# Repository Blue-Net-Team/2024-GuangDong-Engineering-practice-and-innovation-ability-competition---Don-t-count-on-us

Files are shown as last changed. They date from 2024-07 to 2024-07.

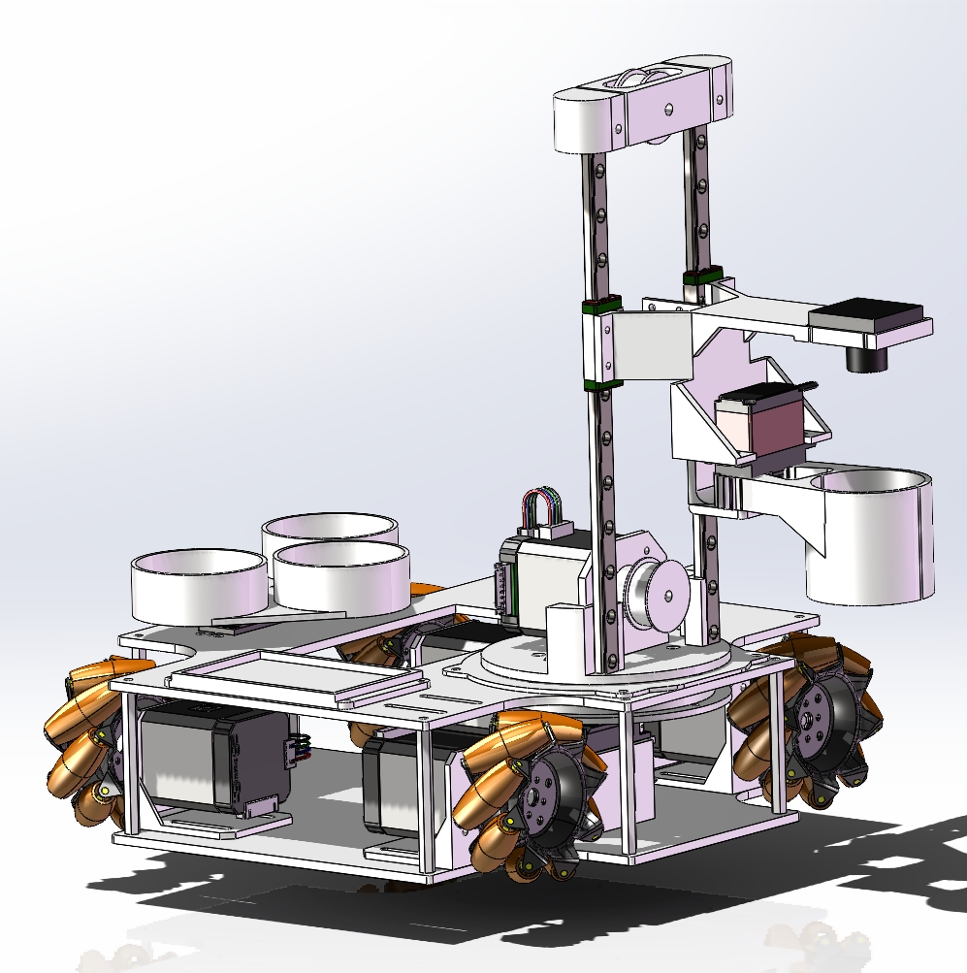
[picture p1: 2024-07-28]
Pic/4.png

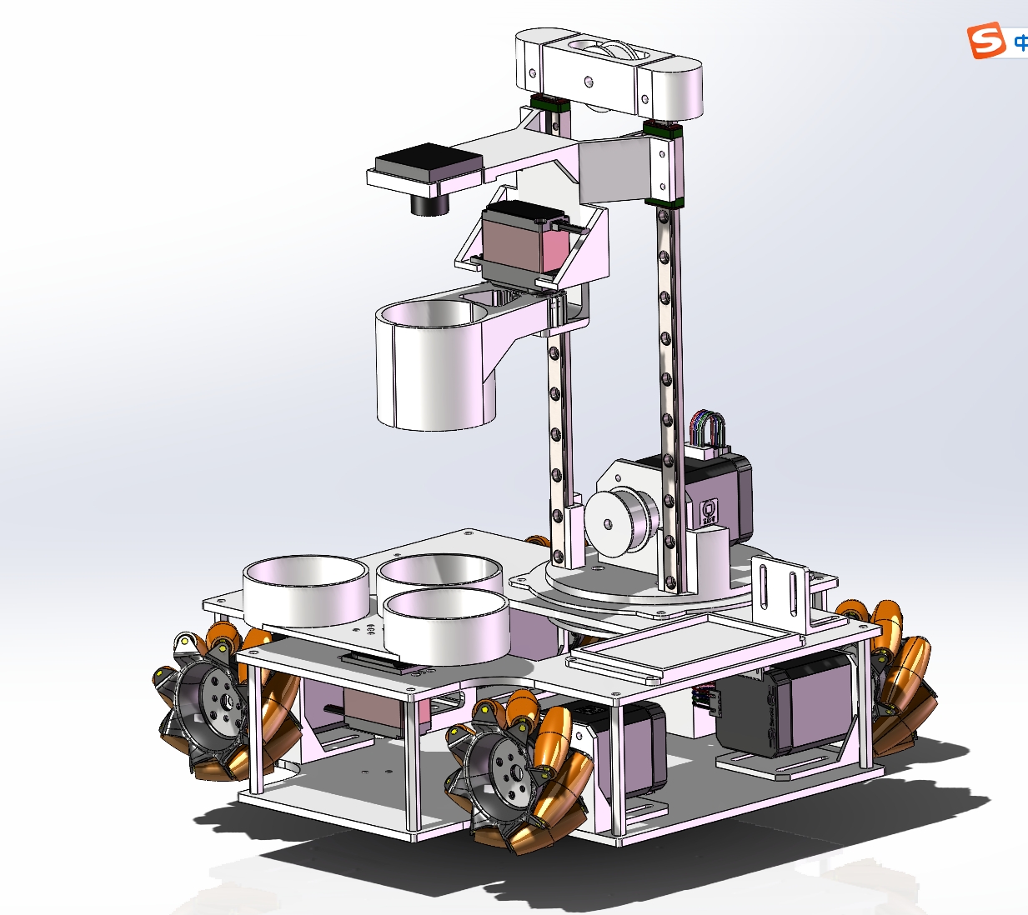
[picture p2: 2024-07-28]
Pic/2.png

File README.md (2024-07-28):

# 2024年工创智慧物流搬运赛道——不要指望我们队

## 1. 项目简介

本项目是针对**2024年工程实践创新大赛 智慧物流搬运**的完整项目，包括代码、电路设计、结构设计等。

## 2. 小队成员

- 吉泧均——结构设计
- [林哲涵](https://gitee.com/purebrandy)——电控设计
- [何云峰](https://gitee.com/iven_he)——视觉识别

## 3. 文件夹说明

本文件夹中包含了一下主要文件夹

- `Vision`：视觉识别代码
- `Embedded`：电控代码
- `Structure`：结构设计(使用SolidWorks2023或者以上版本打开)
- `Doc`: 项目文档
- `Pic`: 模型图片
- `LICENSE`: 项目开源许可证
- `README.md`: 项目说明文件

## 获奖情况

实时是，此代码并未获奖，分析前后原因，视觉方面鲁棒性不够高。在设备方面，升降机构的电机存在不明确的问题，有时候会出现堵转的情况，有时候会直接断电，导致整个设备无法正常运行，这个问题原因仍不明确。

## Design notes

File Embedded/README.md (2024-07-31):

# 2024工创电控部分代码

## 介绍
2024年工创物流车电控部分代码
内容包括
- 闭环步进电机驱动
- 麦克纳姆轮运动学解算
- 270度舵机驱动
- 扫码模块读取解码
- 与数码管显示的通信协议
- 与树莓派视觉的通信协议

## 开发平台
STM32F407VET6

## 开发环境
Keil5 MDK
FreeRTOS

## 开发说明
本代码基于单片机的实时操作系统FreeRTOS开发

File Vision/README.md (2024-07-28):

# 2024年工创智慧物流搬运赛道——不要指望我们队(视觉识别)

## 1. 代码简介

本项目是针对**2024年工程实践创新大赛 智慧物流搬运**的视觉识别代码

## 2. 小队成员

- 吉泧均——结构设计
- [林哲涵](https://gitee.com/purebrandy)——电控设计
- [何云峰](https://gitee.com/iven_he)——视觉识别

## 3. 文件说明

本文件夹中包含了一下主要文件

- `main.py`：项目主文件，封装了所有回应电控stm32的需求的函数
- `img_trans.py`:远程图传文件，其中类
  - `VideoStreaming`是用于传输图像的类，在树莓派上运行
  - `ReceiveImg`是用于接受远程图传图像的类，在本地电脑运行
- `detector.py`：存放识别器的文件，其中类
  - `ColorDetector`是用于识别颜色的颜色识别器
  - `LineDetector`是用于识别直线状态的识别器，包含识别直线角度以及直线距离
- `DEBUG.py`：用于调试的文件，其中类
  - `Debug`是用于调试的类，继承了主文件的类，可以在调试时使用，直接修改主文件的代码就可以在调试时使用
- `UART.py`：串口通信文件，其中类
  - `UART`是用于串口通信的类，继承了`pyserial`库的`Serial`类，添加了**包头包尾**的发送方式以及**整形数据**和**整形数组**的发送方式

## 4. 使用说明

本项目需要在本地电脑和树莓派上都克隆此项目

```bash
git clone https://gitee.com/blue-net-vision/physical-distribution-car.git
```

在远程调试过程中，在树莓派上运行`img_trans.py`文件打开图传服务器，需要注意的是

- **树莓派和本地电脑需要在同一个局域网下**
- **先运行`img_trans.py`文件，再运行`DEBUG.py`文件**
- **`img_trans,py`已经将相关IO输出(print)关闭，如果需要开启需要自行取消注释**

然后打开`DEBUG.py`文件，运行相关的阈值调试函数，在图传调试的时候，将DEBUG实例化的参数改为True;如果不使用图传摄像头，就将DEBUG实例化的参数改为False

### 调试的过程中会产生以下文件

- `R.json`：存放红色阈值的文件
- `G.json`：存放绿色阈值的文件
- `B.json`：存放蓝色阈值的文件
- `line.json`：存放直线canny阈值的文件
- `color_oc.json`：存放物料颜色识别的开闭运算参数的文件
- `line_oc.json`：存放直线识别的开闭运算参数的文件
- `circle1.json`：存放物料盘上夹取物料的基准圆信息的文件
- `radius.json`：在物料盘上夹取物料的时候的最小和最大外接圆识别半径

## 代码解读

在此代码中，以下代码是用于调整图像的范围的，即裁剪图像，过滤无关的区域，使得后续的识别更加准确。

```python
self.img = self.read_cap()
# [130:370, :]是裁剪图像的范围，需要根据具体情况调整
self.img = self.img[130:370, :]
```

### 1. `main.py`——在树莓派上直接运行的主文件

#### 1.1 region 参数加载

在参数加载的region区域，设置了各种识别过程中的参数，包括阈值，开闭运算参数，基准圆信息等。前两个以大写开头的字典视为常量字典，用于在后续的识别过程中使用。

#### 1.2 类Solution

这是一个包含代码顶层抽象逻辑的**解决方案类**，继承了`detector.py`文件中的`ColorDetector`和`LineDetector`类，使后续的代码更加灵活。以大写字母开头的函数在该类中属于最顶层接口，反之为次级接口。

在该类中，可以注意到`__init__`函数中有两个部分，一个是类自身的init，另一个是在`__init__`函数之外编写的`init_part1`,其中，`init_part1`函数是便于后续`DEBUG.py`文件中**调试类**继承时候的超类初始化。

`read_cap`函数是用于读取图传图像的函数，这个函数的设计是为了解决摄像头的ID号突然发生改变导致无法读取图像的问题，并且返回值不再包含`cv2.VideoCapture.read()`返回值中的bool标签，而是直接返回图像。

`send_msg`函数是用于发送串口数据的函数，只需要向里面传递整型、整型数组、字符串等数据即可以从串口发送对应的字符ascii码。其中，整型数组(list/tuple)是针对圆环坐标矫正的数据发送，整型是针对物料夹取信号和直线角度矫正的数据发送。此函数在初期框架搭建的时候具有缺陷，只能使用单一的包头包尾，否则需要针对不同的包头包尾设计不同的发送函数和修饰器。

`Detect_color`函数是用于识别颜色的函数，需要电控提供相关的颜色索引 (0红 1绿 2蓝),返回值是是否识别到这个颜色，只会返回True，如果没有匹配的颜色，会继续循环进行识别。在此处识别的逻辑是，先对图像进行hsv的图像二值化，然后将白色(符合颜色阈值的区域)区域做最小外接圆匹配(相关参数文件位于`radius.json`)，然后圈出的圆再与基准圆(相关参数文件位于`circle1.json`)进行比较，如果两个圆的重叠面积比例(以基准圆面积为分母)大于225行的0.48，就认为匹配到颜色。

`CORRECTION_angle`函数是用于矫正直线角度的，使用此函数需要确保摄像头的视野范围可以**看清楚**基准直线，如果看不清或者看不见的话就不会有返回数据。在此函数中，首先对图像进行canny边缘检测，然后对边缘检测的图像进行霍夫直线检测，最后对检测到的直线进行角度的计算，返回值是直线的角度。244行的90是基准直线的角度，这个数值取决于摄像头摆放的角度。

`LOCATECOLOR`函数是用于矫正色环的函数，使用此函数需要确保摄像头的视野范围可以**看清楚**圆环，如果看不清或者看不见的话就不会有返回数据，而是循环识别，知道识别到圆环。在此函数中，首先对图像进行hsv的图像二值化，进行相关的开闭运算(相关参数文件位于`circle_oc.json`)，然后对图像进行霍夫圆检测，这个过程循环10次，如果没识别到不计入，然后计算平均值，并且用基准圆(相关参数文件位于`circle2.json`)的圆心坐标做差，返回值是圆心坐标的差值。可以直接对基准圆文件进行修改，这样比较方便，其中，X调大的时候，物料摆放偏左， y调小的时候，物料摆放偏下

`__call__`是类的主函数调用，调用方法比较特殊，属于类的特殊函数

```python
# 用以下方法调用__call__函数
Solution()()
```

`circle_intersection_area`函数是用于计算两个圆的重叠面积的函数，用于在`Detect_color`函数中计算两个圆的重叠面积比例，传入尾缀为0的参数是第一个圆的圆心坐标和半径，传入尾缀为1的参数是第二个圆的圆心坐标和半径，返回值是两个圆的重叠面积。

### 2.`detector.py`——存放识别器的文件

本文件识别逻辑比较基础，霍夫算法检测查看csdn或者百度，此处不再解读

### 3.`DEBUG.py`——用于调试的文件

此类有4个顶层接口，用于外界直接调用，`SetCircleThresholds` `SetColorThresholds` `SetLineThresholds`分别用于设置圆环阈值，颜色阈值，直线阈值

底层函数接口简单，不再解读

### 4.`UART.py`——串口通信文件

此代码框架成型早，没有考虑太多问题，一开始将包头包尾封装进修饰器，然后发现不同的条件发送的数据包头包尾应该不同，，所以在后续代码中添加了过多的针对性修饰器和发送函数，导致代码冗余，不够简洁，但是功能齐全，可以直接使用。`read`函数比较完美，重写了父类`sreial`的`read`函数，可以通过包头包尾来读取不定长度的数据，但是每次只能读一个字节，对于`\r\n`的读取不够完美，需要后续优化。

## 获奖情况

实时是，此代码并未获奖，分析前后原因，鲁棒性不够高，并且代码冗余，不够简洁，后续需要优化。与此同时，应该将main文件中225行的最小重叠面积比例调小，以及`ciecle1.json`文件中的基准圆半径调大，这样可以提高识别的鲁棒性。在设备方面，升降机构的电机存在不明确的问题，有时候会出现堵转的情况，有时候会直接断电，导致整个设备无法正常运行，这个问题原因仍不明确。在后续的比赛中，视觉方面决定放弃hsv识别方案，转而使用深度学习的方案，这样可以提高识别的准确性，鲁棒性，以及适应性。

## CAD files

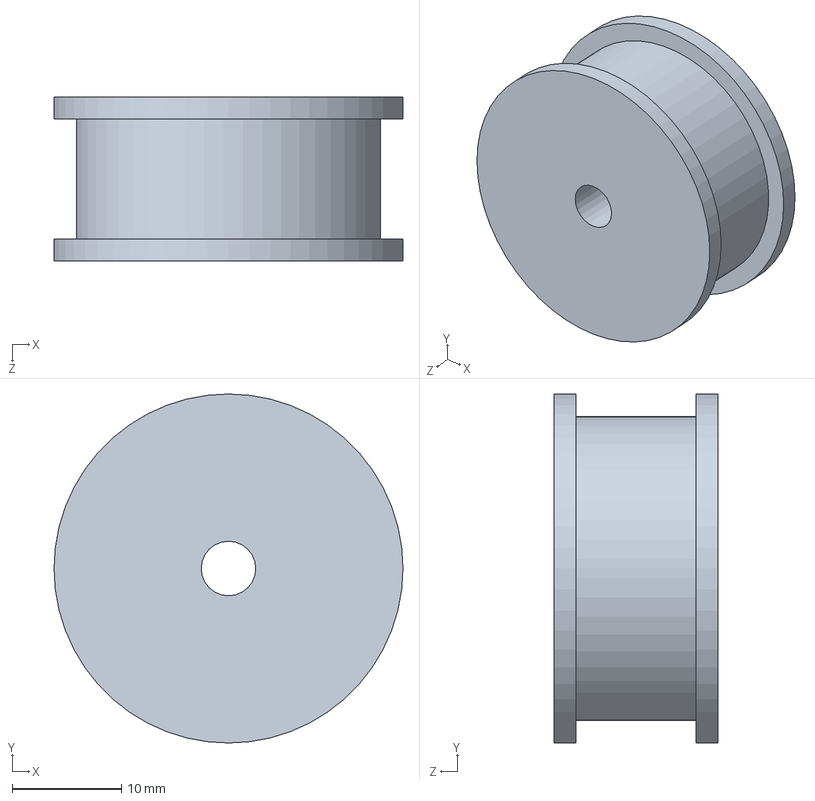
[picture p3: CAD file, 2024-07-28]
Structure/AF同步轮.SLDPRT
32.0 x 32.0 x 15.0 mm

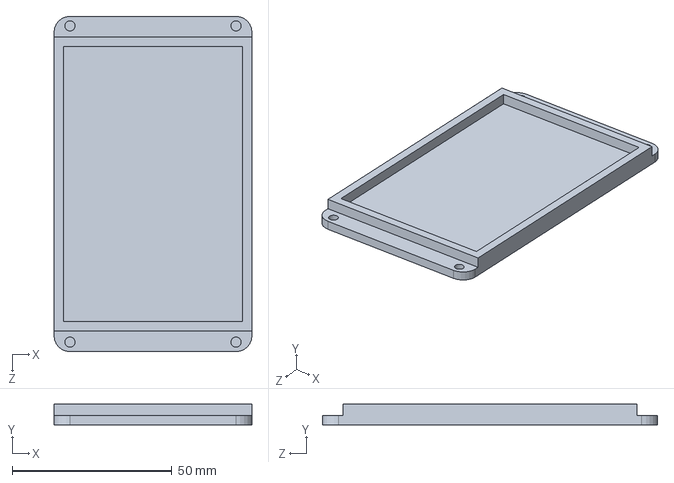
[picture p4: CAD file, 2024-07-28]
Structure/树莓派固定.SLDPRT
62.0 x 6.50 x 105.0 mm

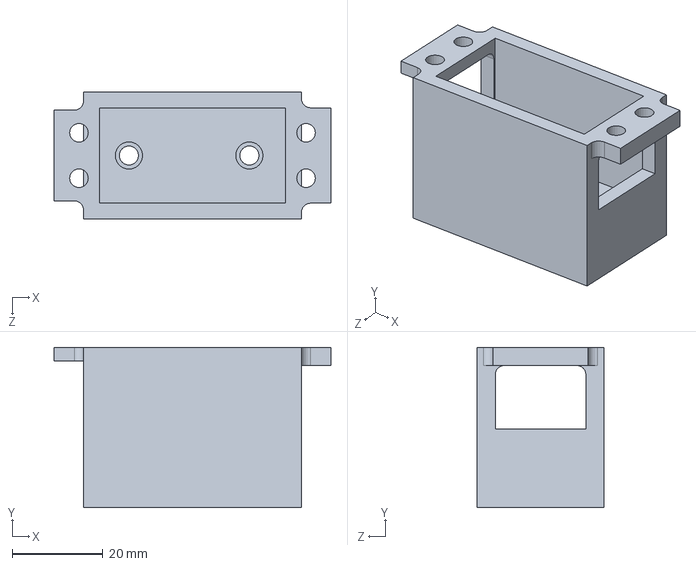
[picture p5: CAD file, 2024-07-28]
Structure/舵机固定支架.SLDPRT
61.0 x 35.3 x 28.0 mm

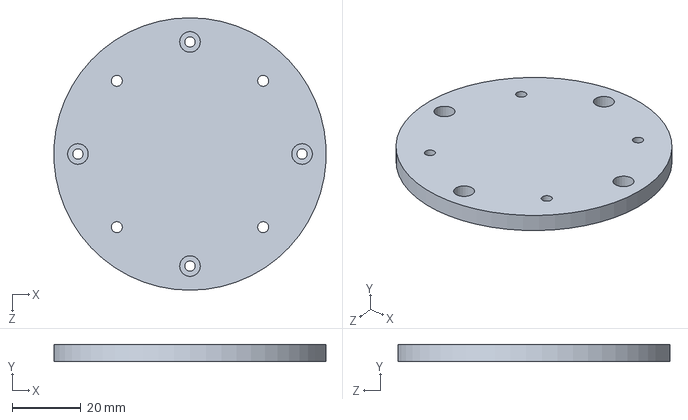
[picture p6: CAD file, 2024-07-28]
Structure/旋转顶盖.SLDPRT
78.9 x 5.00 x 79.0 mm

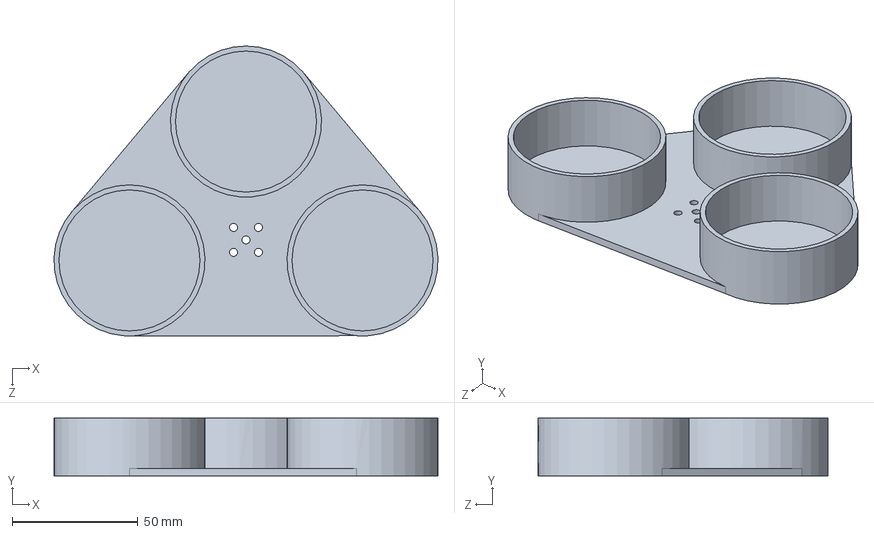
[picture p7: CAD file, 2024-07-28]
Structure/载物盘.SLDPRT
152.5 x 23.0 x 115.2 mm

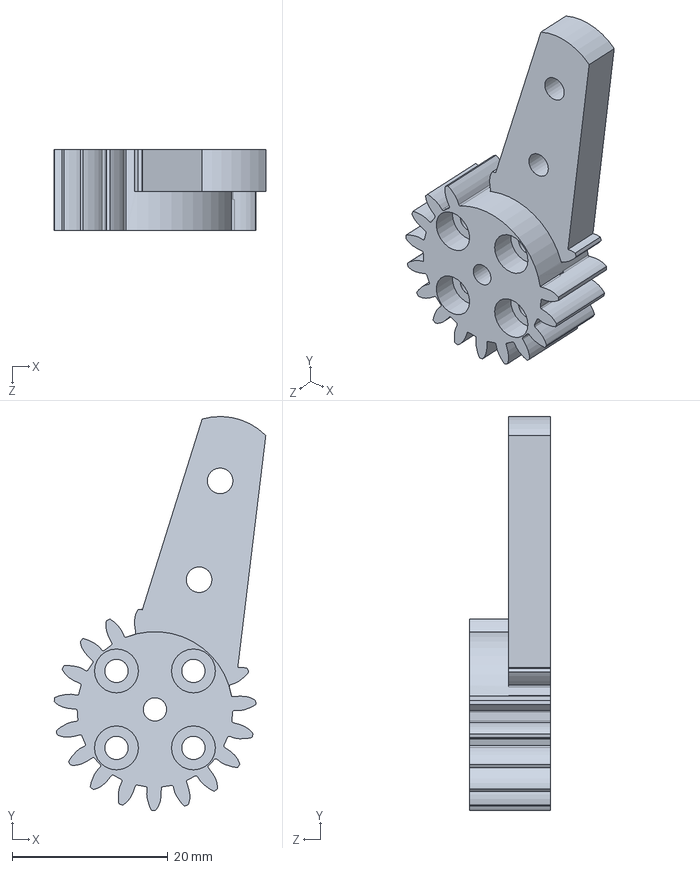
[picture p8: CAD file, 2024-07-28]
Structure/机械爪左便携支架.SLDPRT
27.2 x 50.7 x 10.5 mm

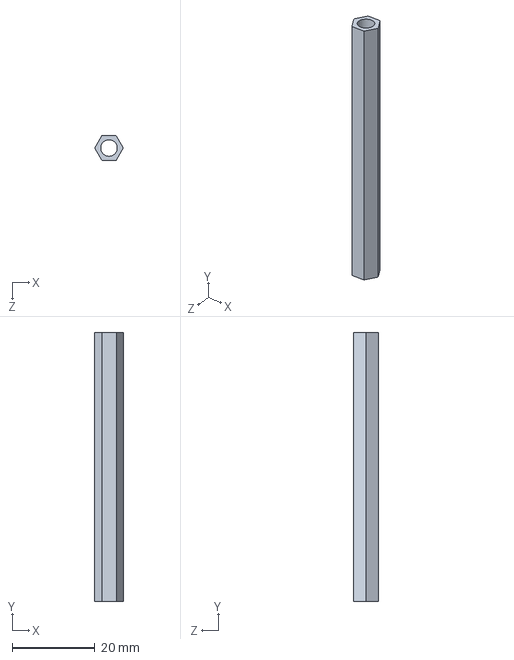
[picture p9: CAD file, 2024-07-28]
Structure/铜柱M4×65.SLDPRT
6.93 x 65.0 x 6.02 mm

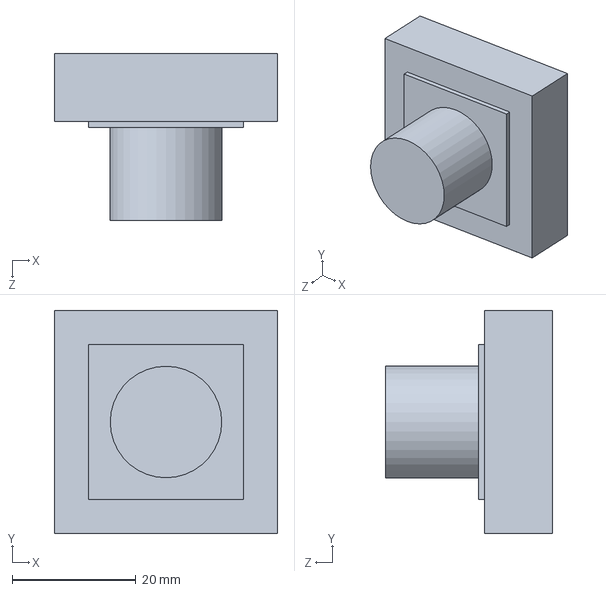
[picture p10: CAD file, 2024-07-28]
Structure/宇宙无敌暴龙之眼.SLDPRT
36.0 x 36.0 x 27.0 mm

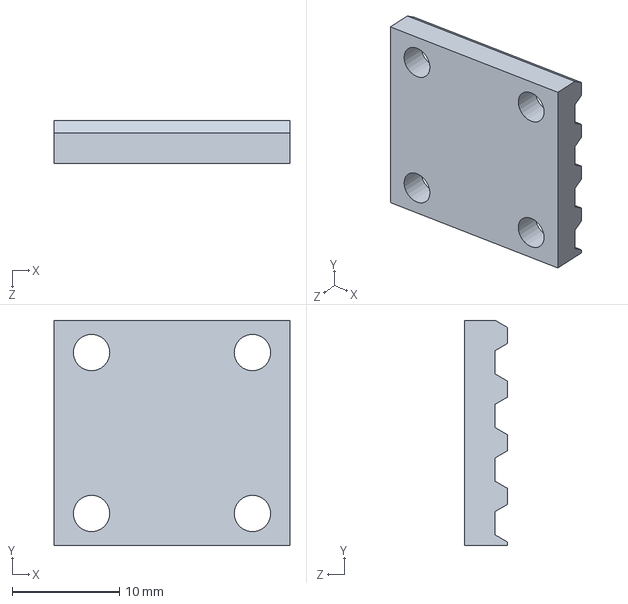
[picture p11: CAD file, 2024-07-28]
Structure/同步带压板.SLDPRT
22.0 x 21.0 x 4.00 mm

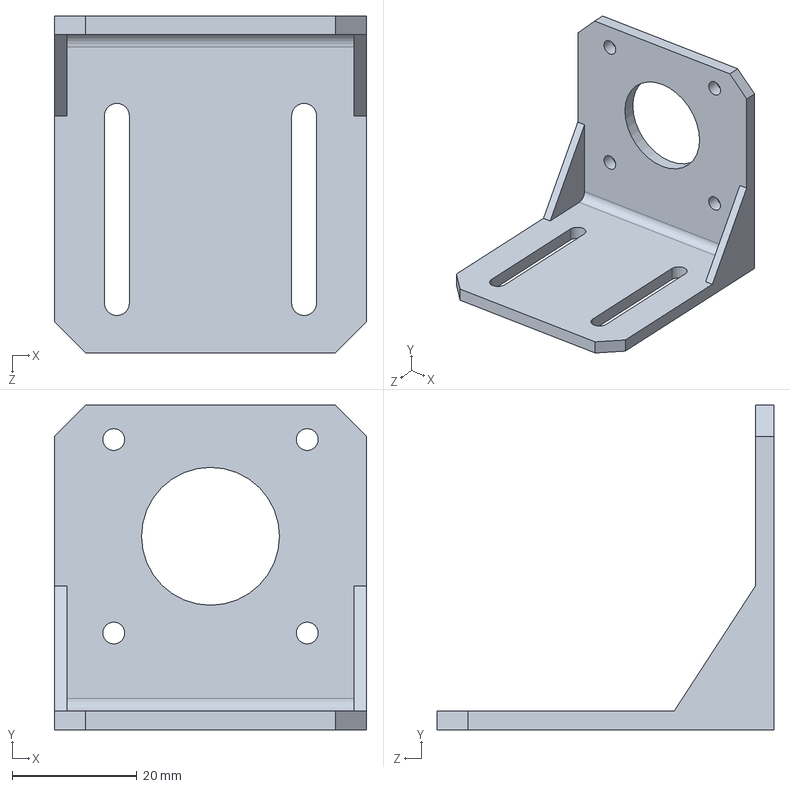
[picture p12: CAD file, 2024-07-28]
Structure/42步进电机支架.SLDPRT
50.0 x 52.0 x 54.0 mm

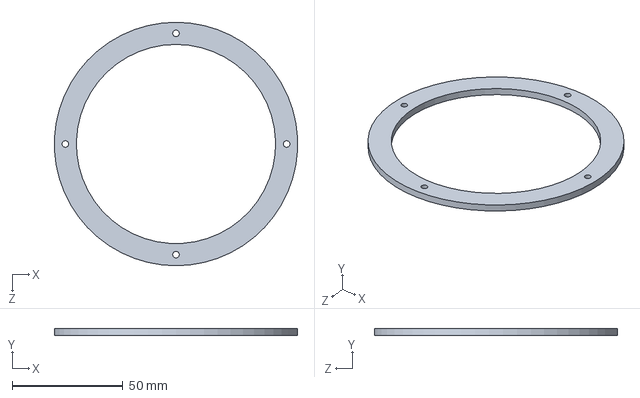
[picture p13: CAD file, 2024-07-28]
Structure/云台底盘.SLDPRT
109.8 x 3.00 x 110.0 mm

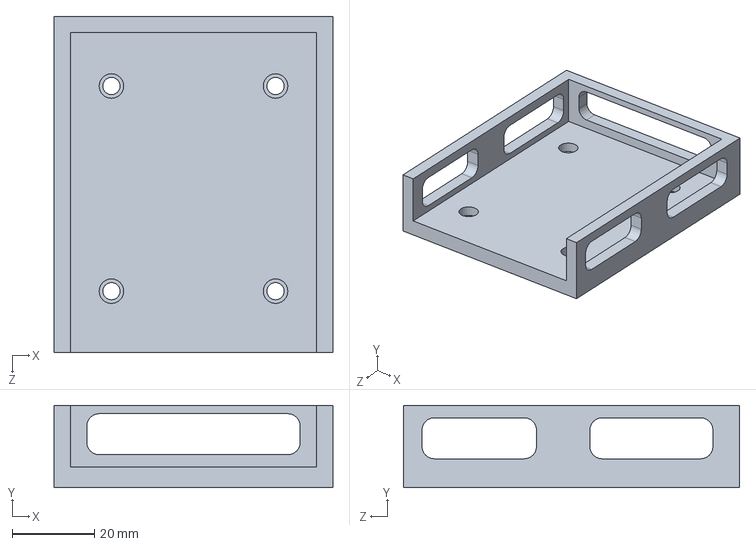
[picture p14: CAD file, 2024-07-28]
Structure/电池支架.SLDPRT
68.0 x 20.0 x 82.0 mm

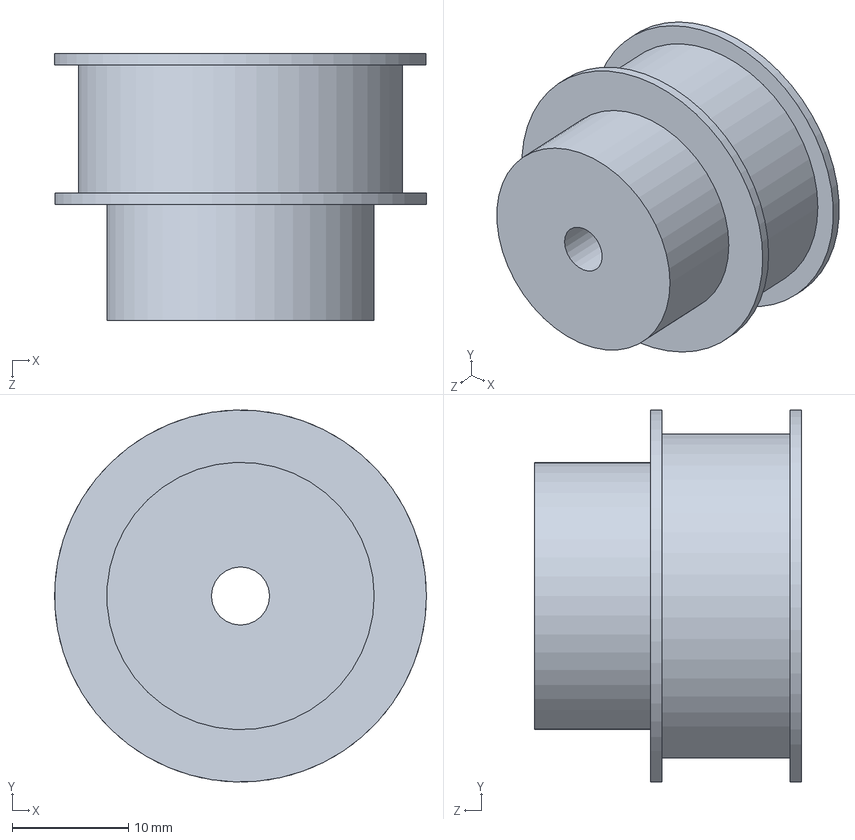
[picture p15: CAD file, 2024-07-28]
Structure/BF同步轮.SLDPRT
32.0 x 32.0 x 23.0 mm

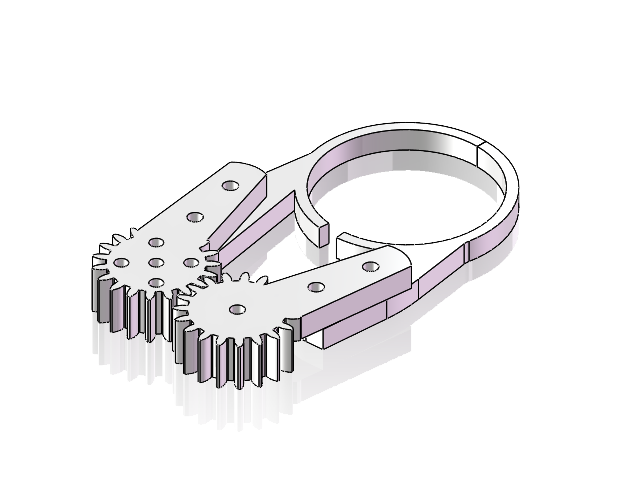
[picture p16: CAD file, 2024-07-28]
Structure/机械爪装配.SLDASM
机械爪左便携支架
机械爪右便携支架
便携爪子初始 x 2

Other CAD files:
Structure/机械爪2.SLDASM
Structure/MGN9-250.SLDASM
Structure/42步进电机.SLDASM
Structure/mecanum wheel.SLDASM
Structure/上同步轮固定.SLDPRT
Structure/上板.SLDPRT
Structure/下固定板.SLDPRT
Structure/二维码模块上层固定架2.SLDPRT
Structure/二维码模块固定板.SLDPRT
Structure/云台顶盘.SLDPRT
Structure/便携爪子初始.SLDPRT
Structure/便携爪子初始加长.SLDPRT
Structure/升降链接6.SLDPRT
Structure/同步轮.SLDPRT
Structure/底板.SLDPRT
Structure/摄像头固定支架.SLDPRT
Structure/摄像头平台.SLDPRT
Structure/旋转底层.SLDPRT
Structure/机械爪右2.SLDPRT
Structure/机械爪右便携支架.SLDPRT
Structure/机械爪右初始.SLDPRT
Structure/机械爪左2.SLDPRT
Structure/机械爪左初始.SLDPRT
Structure/树莓派固定2.SLDPRT
Structure/法兰盘.SLDPRT
Structure/滑台.SLDPRT
Structure/滑轨.SLDPRT
Structure/爪子2.SLDPRT
Structure/物料.SLDPRT
Structure/电池支架2.SLDPRT
Structure/舵机.SLDPRT
Structure/轴承.SLDPRT

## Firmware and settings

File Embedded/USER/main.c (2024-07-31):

#include "main.h"

/********************
	声明：
	绝大部分移植于gitee蓝网电控库 "@D2zling"
	具体详细参照gitee蓝网电控库“2024工创电控代码”
*******************/

/*
r"""
*********************************************
? ? ? ? ? ? ? ? ? ?_ooOoo_
? ? ? ? ? ? ? ? ? o8888888o
? ? ? ? ? ? ? ? ? 88" . "88
? ? ? ? ? ? ? ? ? (| -_- |)
? ? ? ? ? ? ? ? ? O\ ?= ?/O
? ? ? ? ? ? ? ?____/`---'\____
? ? ? ? ? ? ?.' ?\\| ? ? |// ?`.
? ? ? ? ? ? / ?\\||| ?: ?|||// ?\
? ? ? ? ? ?/ ?_||||| -:- |||||- ?\
? ? ? ? ? ?| ? | \\\ ?- ?/// | ? |
? ? ? ? ? ?| \_| ?''\---/'' ?| ? |
? ? ? ? ? ?\ ?.-\__ ?`-` ?___/-. /
? ? ? ? ?___`. .' ?/--.--\ ?`. . __
? ? ? ."" '&lt; ?`.___\_&lt;|>_/___.' ?>'"".
? ? ?| | : ?`- \`.;`\ _ /`;.`/ - ` : | |
? ? ?\ ?\ `-. ? \_ __\ /__ _/ ? .-` / ?/
======`-.____`-.___\_____/___.-`____.-'======
? ? ? ? ? ? ? ? ? ?`=---='

? ? ? ? ? ? 佛祖保佑 ? ? ? 工创省一
^^^^^^^^^^^^^^^^^^^^^^^^^^^^^^^^^^^^^^^^^^^^^
"""
*/

/*
舵机      PD12	   PD13	   PD14	   
通道	    CH1	     CH2		 CH3		   
对应      爪子     货舱    云台
ServoNum   0        1       2
*/

int main(void)
{
	NVIC_PriorityGroupConfig(NVIC_PriorityGroup_4);			//设置系统中断优先级分组4
	delay_init(168);										  //延时初始化
	usart3_init(9600);										//树莓派通信端口
	scan_qr_code_Init();									//扫码初始化
	digital_tube_Init();									//数码管模块初始化
	MOTOR_UP_Down_Init();									//脉冲控制升降爪初始化
	usart_ctrl_steeping_motor_Init();			//串口控制步进电机初始化
	servo_Init(20000 - 1, 84 - 1);				//舵机控制初始化

	package_Init();											  //串口数据包软件初始化
	motor_soft_Init();										//电机软件初始化
	
	//舵机启动复位
	ServoAngle(0,Claw_Open); //150 228 205 130 Claw_Open Claw_Catch Claw_Open_Small Claw_Open_Big
	ServoAngle(1,Warehouse_running); //108 10 208 120 Warehouse_1 Warehouse_2 Warehouse_3 Warehouse_running
	ServoAngle(2,Clound_Reset); //90 268  Cloude_Work  Clound_Reset
}

void tast_loop(void)
{
  static char* qr_data = NULL;						//扫码数据包
	static int* move = NULL;							//半成品/成品区动作
	static u8 *color_data = NULL;						//颜色数据

	char i;												//计数变量
	int angle_warehouse = 108;
	
	delay_ms(2000);	//等待电机启动
	                                                                                                                                                  ;
	while(1)
	{

//		ServoAngle(2,Cloude_Work);
					
//			while(1);
		
		/*********第一轮**********/
		{	//**前往原料区**//
		change_xyw_speed_no_quene(0,-91,0);//-90
		delay_ms(300);

		change_xyw_speed_no_quene(157,0,0);
		delay_ms(1200);
		
		change_xyw_speed_no_quene(0,0,0);
		delay_ms(1000);
		
		while(qr_data == NULL) qr_data = get_qr_code_data();//获取二维码并显示
		digital_tube_Display(qr_data);

		delay_ms(200);
			
		ServoAngle(0,Claw_Open);//爪子开始工作
		ServoAngle(2,Cloude_Work);//云台开始工作
		
		change_xyw_speed_no_quene(146,26,0);
		delay_ms(1200);

		change_xyw_speed_no_quene(0,0,0);
		delay_ms(100);
		
		delay_ms(500);
		}
					
		//**一轮获取物料**//
		for(i = 0;i <= 2; i++)
		{
			SendByte('c',qr_data[i]-1);//呼叫树莓先生识别颜色
			//调试：可注释掉假装识别到
			while(1)
			{
				color_data = get_color_data();
				if(color_data[0] == '1')
				{
					color_data = NULL;
					break;
				}
			}
			//按顺序决定货仓舵机角度
			if(i == 0) 		angle_warehouse = Warehouse_1;
			else if(i == 1) 	angle_warehouse = Warehouse_2;
			else if(i == 2) 	angle_warehouse = Warehouse_3;
			ServoAngle(1,angle_warehouse);//108 10 203
			
			if(i <= 1)
			{
				Claw_Catch_material();//获取原料
				delay_ms(500);
			}
			if(i == 2)
			{
					Claw_Up_Down(0,Material_Height);//下降
					ServoAngle(0,Claw_Catch);//抓取角度：225
					delay_ms(300);
					ServoAngle(2,Clound_Reset);//云台旋转放置：270
					Claw_Up_Down(1,Material_Height);//升高
					Claw_Up_Down(0,Put_Height);//下降
					ServoAngle(0,Claw_Open_Small);//松开小角度：200
					delay_ms(100);
					Claw_Up_Down(1,Put_Height);//升高
					ServoAngle(0,Claw_Open);
					//放置完最后一个物料后，边走边复位云台
					change_xyw_speed_no_quene(132,0,-65);ServoAngle(1,Warehouse_running);
					delay_ms(1200);
					change_xyw_speed_no_quene(0,0,0);ServoAngle(2,Cloude_Work);
					delay_ms(600);
			}

		}

		{//**一轮物料盘到暂存区**//

			if(qr_data[0] == '1')//根据二维码数字决定先到哪个位置
			{	
				change_xyw_speed_no_quene(100,0,0);
				delay_ms(1100);
				change_xyw_speed_no_quene(0,0,0);
				delay_ms(100);
			}
			else if(qr_data[0] == '2')
			{	
				change_xyw_speed_no_quene(100,0,0);
				delay_ms(1400);
				change_xyw_speed_no_quene(0,0,0);
				delay_ms(100);
			}
			else if(qr_data[0] == '3') 	
			{
				change_xyw_speed_no_quene(100,0,0);
				delay_ms(1800);
				change_xyw_speed_no_quene(0,0,0);
				delay_ms(100);
			}
		
		}
		
		//**一轮半成品区放置三个物料**//
		for(char i = 0; i <= 2; i++)
		{
			move = get_way(qr_data[i]);//获取下一个目标
			change_xyw_speed_no_quene(move[1],0,0);
			delay_ms(move[0]);

			change_xyw_speed_no_quene(0,0,0);
			delay_ms(100);
			
			Claw_Up_Down(0,Camera_Height);//降下摄像头
			vTaskDelay(500);
			
			for(char j =0; j<10; j++)//刷新串口数据
			{SendByte('C',qr_data[i]-1);delay_ms(100);}
			
			location_task(qr_data[i]-1);//树莓先生的色环矫正环节

			Claw_Up_Down(1,Camera_Height);//升起摄像头
			delay_ms(500);
			
			//按顺序决定货仓舵机角度
			if(i == 0) 		angle_warehouse = Warehouse_1;
			else if(i == 1) 	angle_warehouse = Warehouse_2;
			else if(i == 2) 	angle_warehouse = Warehouse_3;
			ServoAngle(1,angle_warehouse);//108 10 203
			
			PutOn_Ground();//放置物料到地上	

		}

		//**半成品区捡起三个物料**//
		for(char i = 0; i < 3; i++)
		{
			move = get_way(qr_data[i]);		//获取下一个目标
			change_xyw_speed_no_quene(move[1],0,0);
			delay_ms(move[0]);

			change_xyw_speed_no_quene(0,0,0);
			delay_ms(100);
			
			//按顺序决定货仓舵机角度
			if(i == 0) 		angle_warehouse = Warehouse_1;
			else if(i == 1) 	angle_warehouse = Warehouse_2;
			else if(i == 2) 	angle_warehouse = Warehouse_3;
			ServoAngle(1,angle_warehouse);//108 10 203 
			
			Catch_From_Ground();//从地面取回物料放回货仓
			
			delay_ms(500);
		}
		
		ServoAngle(1,Warehouse_running);

		{//**暂存区到成品区**//
			change_xyw_speed_no_quene(0,-100,0);//-90
			delay_ms(200);
			change_xyw_speed_no_quene(0,0,0);//-90
			delay_ms(300);
			
			
			//根据二维码数字补回距离
			if(qr_data[2] == '1')  
			{change_xyw_speed_no_quene(100,0,0);delay_ms(670);}
			else if(qr_data[2] == '2') 
			{change_xyw_speed_no_quene(100,0,0);delay_ms(335);}
			else if(qr_data[2] == '3') 
			{change_xyw_speed_no_quene(0,0,0);delay_ms(100);}

			change_xyw_speed_no_quene(0,0,0);delay_ms(500);
			
			change_xyw_speed_no_quene(133,0,-65);
			delay_ms(1300);
			change_xyw_speed_no_quene(0,0,0);
			delay_ms(500);
			
			//直线矫正
			Claw_Up_Down(0,Line_Height);//降下摄像头
			delay_ms(500);
			Line_task();
			Claw_Up_Down(1,Line_Height);//升起摄像头
			delay_ms(500);

			//根据二维码数字决定到哪个位置
			if(qr_data[0] == '1') 		
			{	
				change_xyw_speed_no_quene(95,12,0);
				delay_ms(870);
				change_xyw_speed_no_quene(0,0,0);
			}
			else if(qr_data[0] == '2')
			{	
				change_xyw_speed_no_quene(100,15,0);
				delay_ms(1150);
				change_xyw_speed_no_quene(0,0,0);
				delay_ms(100);
			}
			else if(qr_data[0] == '3') 	
			{
				change_xyw_speed_no_quene(100,10,0);
				delay_ms(1600);
				change_xyw_speed_no_quene(0,0,0);
				delay_ms(100);
			}
			change_xyw_speed_no_quene(0,0,0);
			vTaskDelay(500);
		
		//*成品区放置物料*//
			 for(char i = 0; i < 3; i++)
		{
			move = get_way(qr_data[i]);		//获取下一个目标
			change_xyw_speed_no_quene(move[1], 0, 0);
			delay_ms(move[0]);
			
			change_xyw_speed_no_quene(0,0,0);
			delay_ms(100);
			
			Claw_Up_Down(0,Camera_Height);//降下摄像头
			delay_ms(500);
			
			for(char j =0; j<10; j++)//刷新串口数据
			{SendByte('C',qr_data[i]-1);delay_ms(100);}
			
			location_task(qr_data[i]-1);//色环矫正

			Claw_Up_Down(1,Camera_Height);//升起摄像头
			delay_ms(500);
			
			//按顺序决定货仓舵机角度
			if(i == 0) 		angle_warehouse = Warehouse_1;
			else if(i == 1) 	angle_warehouse = Warehouse_2;
			else if(i == 2) 	angle_warehouse = Warehouse_3;
			ServoAngle(1,angle_warehouse);//108 10 203
			
			PutOn_Ground();//放置物料到地上
		}
			 
		ServoAngle(1,Warehouse_running);
		
	}
		//复位count
		 for(char i = 0; i < 3; i++)
				move = get_way(qr_data[i]);
	
			if(qr_data[2] == '1') //根据二维码数字补全距离
				{change_xyw_speed_no_quene(50,0,0);delay_ms(100);}
			else if(qr_data[2] == '2') 
				{change_xyw_speed_no_quene(-100,0,0);delay_ms(350);}
			else if(qr_data[2] == '3') 
				{change_xyw_speed_no_quene(-100,0,0);delay_ms(690);}

			change_xyw_speed_no_quene(0,0,0);delay_ms(300);
		 
		 {//**回到原料区**//			 

			 change_xyw_speed_no_quene(-100,-70,0);
			 delay_ms(500);
			 
			 change_xyw_speed_no_quene(-100,15,0);
			 delay_ms(450);
		 
			 change_xyw_speed_no_quene(0,0,0);
			 delay_ms(500);
			 
			 change_xyw_speed_no_quene(-93,0,66);
			 delay_ms(1200);
			 
			 change_xyw_speed_no_quene(0,0,0);
			 delay_ms(600);  
			 
			  //直线矫正
			 Claw_Up_Down(0,Line_Height);//降下摄像头
			 delay_ms(500);
			 Line_task();
			 Claw_Up_Down(1,Line_Height);//升起摄像头
			 delay_ms(500);
			 
			 change_xyw_speed_no_quene(-150,0,0);
			 delay_ms(1400);
			 
			 change_xyw_speed_no_quene(0,0,0);
			 delay_ms(400);
			 
			 change_xyw_speed_no_quene(-114,0,55);
			 delay_ms(1450);
			 
			 change_xyw_speed_no_quene(0,0,0);
			 delay_ms(400);
			 
			change_xyw_speed_no_quene(-100,0,0);
			 delay_ms(130);
			 
			 change_xyw_speed_no_quene(0,0,0);
			 delay_ms(600);

		 }
		 
		 //********第二轮********//
		 
		 {//二轮原料获取
			for(char j = 0; j < 10 ;j++)//刷新串口数据
			 {
				 SendByte('c',qr_data[3] - 1);
				 color_data = get_color_data();
				 delay_ms(100);
			 }
			
			 
			for(i = 3;i <= 5; i++)
		{
			
			SendByte('c',qr_data[i] - 1);//颜色判断
			
			while(1)
			{
				color_data = get_color_data();
				if(color_data[0] == '1')
				{
					color_data = NULL;
					break;
				}
			}
			//按顺序决定货仓舵机角度
			if(i == 3) 		angle_warehouse = Warehouse_1;
			else if(i == 4) 	angle_warehouse = Warehouse_2;
			else if(i == 5) 	angle_warehouse = Warehouse_3;
			ServoAngle(1,angle_warehouse);//108 10 203
				
				if(i <= 4)
			{
				Claw_Catch_material();//获取原料
				delay_ms(500);
			}
			if(i == 5)
			{
					Claw_Up_Down(0,Material_Height);//下降
					ServoAngle(0,Claw_Catch);//抓取角度：225
					delay_ms(300);
				
					ServoAngle(2,Clound_Reset);//云台旋转放置：270
				
					Claw_Up_Down(1,Material_Height);//升高
				
					Claw_Up_Down(0,Put_Height);//下降
				
					ServoAngle(0,Claw_Open_Small);//松开小角度：200
					delay_ms(100);
				
					Claw_Up_Down(1,Put_Height);//升高
					ServoAngle(0,Claw_Open);
				
					//放置完最后一个物料后，边走边复位云台
					change_xyw_speed_no_quene(118,0,-70);ServoAngle(1,Warehouse_running);
					delay_ms(1200);
				
					change_xyw_speed_no_quene(0,0,0);ServoAngle(2,Cloude_Work);
					delay_ms(600);

			}
		}
			
		 }
		
		 {//**第二轮原料区到暂存区**//
				
			if(qr_data[3] == '1')//根据二维码数字决定先到哪个位置
			{	
				change_xyw_speed_no_quene(100,0,0);
				delay_ms(1200);
				change_xyw_speed_no_quene(0,0,0);
				delay_ms(100);
			}
			else if(qr_data[3] == '2')
			{	
				change_xyw_speed_no_quene(100,0,0);
				delay_ms(1500);
				change_xyw_speed_no_quene(0,0,0);
				delay_ms(100);
			}
			else if(qr_data[3] == '3') 	
			{
				change_xyw_speed_no_quene(100,0,0);
				delay_ms(1900);
				change_xyw_speed_no_quene(0,0,0);
				delay_ms(100);
			}
		
		}
		
		//**第二轮在半成品区放置三个物料**//
		for(char i = 3; i <= 5; i++)
		{
			move = get_way(qr_data[i]);//获取下一个目标
			change_xyw_speed_no_quene(move[1],0,0);
			delay_ms(move[0]);

			change_xyw_speed_no_quene(0,0,0);
			delay_ms(100);
			
			Claw_Up_Down(0,Camera_Height);//降下摄像头
			delay_ms(500);
			
			for(char j = 0; j < 5; j++)//刷新串口数据
				{SendByte('C',qr_data[i]-1);delay_ms(100);}
			
			location_task(qr_data[i]-1);//树莓先生的色环矫正环节

			Claw_Up_Down(1,Camera_Height);//升起摄像头
			delay_ms(500);
			
			//按顺序决定货仓舵机角度
			if(i == 3) 		angle_warehouse = Warehouse_1;
			else if(i == 4) 	angle_warehouse = Warehouse_2;
			else if(i == 5) 	angle_warehouse = Warehouse_3;
			ServoAngle(1,angle_warehouse);//108 10 203
			
			PutOn_Ground();//放置物料到地上	

		}

		//**第二轮半成品区捡起三个物料**//
		for(char i = 3; i <= 5; i++)
		{
			move = get_way(qr_data[i]);		//获取下一个目标
			change_xyw_speed_no_quene(move[1],0,0);
			delay_ms(move[0]);

			change_xyw_speed_no_quene(0,0,0);
			delay_ms(100);
			
			//按顺序决定货仓舵机角度
			if(i == 3) 		angle_warehouse = Warehouse_1;
			else if(i == 4) 	angle_warehouse = Warehouse_2;
			else if(i == 5) 	angle_warehouse = Warehouse_3;
			ServoAngle(1,angle_warehouse);//108 10 203 
			
			Catch_From_Ground();//从地面取回物料放回货仓
			
			delay_ms(500);
		}
		
		ServoAngle(1,Warehouse_running);

		{//**第二轮暂存区到成品区**//
			
			change_xyw_speed_no_quene(0,-100,0);
			delay_ms(200);
			change_xyw_speed_no_quene(0,0,0);
			delay_ms(300);
			
			//根据二维码数字补回距离
			if(qr_data[5] == '1')  
			{change_xyw_speed_no_quene(100,0,0);delay_ms(800);}
			else if(qr_data[5] == '2') 
			{change_xyw_speed_no_quene(100,0,0);delay_ms(500);}
			else if(qr_data[5] == '3') 
			{change_xyw_speed_no_quene(100,0,0);delay_ms(100);}

			change_xyw_speed_no_quene(0,0,0);delay_ms(500);
			
			change_xyw_speed_no_quene(125,0,-65);
			delay_ms(1200);
			change_xyw_speed_no_quene(0,0,0);
			delay_ms(500);
			
			//直线矫正
			Claw_Up_Down(0,Line_Height);//降下摄像头
			delay_ms(500);
			Line_task();
			Claw_Up_Down(1,Line_Height);//升起摄像头
			delay_ms(500);
	
			//根据二维码数字决定到哪个位置
			if(qr_data[3] == '1') 		
			{	
				change_xyw_speed_no_quene(95,12,0);
				delay_ms(900);
				change_xyw_speed_no_quene(0,0,0);
			}
			else if(qr_data[3] == '2')
			{	
				change_xyw_speed_no_quene(100,10,0);
				delay_ms(1400);
				change_xyw_speed_no_quene(0,0,0);
				delay_ms(100);
			}
			else if(qr_data[3] == '3') 	
			{
				change_xyw_speed_no_quene(100,8,0);
				delay_ms(1700);
				change_xyw_speed_no_quene(0,0,0);
				delay_ms(100);
			}
			change_xyw_speed_no_quene(0,0,0);
			vTaskDelay(500);
			
		
		//*第二轮成品区码垛*//
			 for(char i = 3; i <= 5; i++)
		{
			move = get_way(qr_data[i]);		//获取下一个目标
			change_xyw_speed_no_quene(move[1], 0, 0);
			delay_ms(move[0]);
			
			change_xyw_speed_no_quene(0,0,0);
			delay_ms(100);
			
			Claw_Up_Down(0,Camera_Height);//降下摄像头
			delay_ms(500);
			
			for(char j = 0; j < 10; j++)//刷新串口数据
			{SendByte('C',qr_data[i]-1);delay_ms(100);}
			
			location_task(qr_data[i]-1);//色环矫正

			Claw_Up_Down(1,Camera_Height);//升起摄像头
			delay_ms(500);
			
			//按顺序决定货仓舵机角度
			if(i == 3) 		angle_warehouse = Warehouse_1;
			else if(i == 4) 	angle_warehouse = Warehouse_2;
			else if(i == 5) 	angle_warehouse = Warehouse_3;
			ServoAngle(1,angle_warehouse);//108 10 203
			
			Stacking_Material();//码垛
		}
			 
			ServoAngle(1,Warehouse_running);
	}
		
			//根据二维码数字补全距离
			if(qr_data[5] == '3') 
				{change_xyw_speed_no_quene(100,0,0);delay_ms(100);}
			else if(qr_data[5] == '2') 
				{change_xyw_speed_no_quene(100,0,0);delay_ms(350);}
			else if(qr_data[5] == '1') 
				{change_xyw_speed_no_quene(100,0,0);delay_ms(690);}
				
			{//**返屋企**//
			  change_xyw_speed_no_quene(0,0,0);
			 delay_ms(500);
			 
			 change_xyw_speed_no_quene(100,-70,0);
			 delay_ms(500);
			 
			 change_xyw_speed_no_quene(100,15,0);
			 delay_ms(450);
			 
			 change_xyw_speed_no_quene(0,0,0);
			 delay_ms(500);
			 
			 //直线矫正
			 Claw_Up_Down(0,Line_Height);//降下摄像头
			 delay_ms(500);
			 Line_task();
			 Claw_Up_Down(1,Line_Height);//升起摄像头
			 delay_ms(500);
			 
			 ServoAngle(0,Claw_Open); //150 225 Claw_Open Claw_Catch Claw_Open_Small
			 ServoAngle(1,Warehouse_1); //108 10 208 Warehouse_1 Warehouse_2 Warehouse_3
			 ServoAngle(2,Clound_Reset); //90 268  Cloude_Work  Clound_Reset
				
			 change_xyw_speed_no_quene(130,0,-66);
			 delay_ms(1200);
			 
			 change_xyw_speed_no_quene(0,0,0);
			 delay_ms(600);
			 
			 change_xyw_speed_no_quene(150,0,0);
			 delay_ms(1600);
				
			 change_xyw_speed_no_quene(150,17,0);
			 delay_ms(650);

			 change_xyw_speed_no_quene(0,0,0);
			 delay_ms(500);
		 }
		
		 
		change_xyw_speed_no_quene(0,0,0);//停车
		delay_ms(100);
		 
/*
r"""
*********************************************
? ? ? ? ? ? ? ? ? ?_ooOoo_
? ? ? ? ? ? ? ? ? o8888888o
? ? ? ? ? ? ? ? ? 88" . "88
? ? ? ? ? ? ? ? ? (| -_- |)
? ? ? ? ? ? ? ? ? O\ ?= ?/O
? ? ? ? ? ? ? ?____/`---'\____
? ? ? ? ? ? ?.' ?\\| ? ? |// ?`.
? ? ? ? ? ? / ?\\||| ?: ?|||// ?\
? ? ? ? ? ?/ ?_||||| -:- |||||- ?\
? ? ? ? ? ?| ? | \\\ ?- ?/// | ? |
? ? ? ? ? ?| \_| ?''\---/'' ?| ? |
? ? ? ? ? ?\ ?.-\__ ?`-` ?___/-. /
? ? ? ? ?___`. .' ?/--.--\ ?`. . __
? ? ? ."" '&lt; ?`.___\_&lt;|>_/___.' ?>'"".
? ? ?| | : ?`- \`.;`\ _ /`;.`/ - ` : | |
? ? ?\ ?\ `-. ? \_ __\ /__ _/ ? .-` / ?/
======`-.____`-.___\_____/___.-`____.-'======
? ? ? ? ? ? ? ? ? ?`=---='

? ? ? ? ? ? 佛祖保佑 ? ? ? 工创省一
^^^^^^^^^^^^^^^^^^^^^^^^^^^^^^^^^^^^^^^^^^^^^
"""
*/
		 while(1);
	}
}

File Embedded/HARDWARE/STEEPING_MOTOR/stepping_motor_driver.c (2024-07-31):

#include "stepping_motor_driver.h"


//串口控制步进电机初始化
void usart_ctrl_steeping_motor_Init()
{
	uart4_init(115200);										//底盘电机控制串口
}

//底盘电机控制函数
void usart_ctrl_chassis_motor(steeping_motor motor, char speed_or_distence)
{
	if(speed_or_distence == 0)	//距离模式
	{
		char ctrl_location_arr[13] = {	motor.motor_ID, 				//地址
										0xfd, 							//指令码
										motor.motor_direction, 			//方向
										motor.motor_speed >> 8, 		//速度高8位
										motor.motor_speed, 				//速度低8位
										motor.motor_acc_speed,			//加速度档位
										motor.motor_pulse_num >> 24,
										motor.motor_pulse_num >> 16, 	//脉冲数高16位
										motor.motor_pulse_num >> 8,
										motor.motor_pulse_num , 		//脉冲数低16位
										0x00,							//相对，绝对位置
										motor.synchronous,				//多机同步
										0x6b};							//校验

		for(char i = 0; i < 13; i++)
		{
			while((UART4->SR&0X40)==0);
			UART4->DR = ctrl_location_arr[i];
		}
	}
	else if(speed_or_distence == 1)
	{
		char ctrl_speed_arr[8] = {	motor.motor_ID, 					//地址
									0xf6, 								//指令码
									motor.motor_direction, 				//方向
									motor.motor_speed >> 8, 			//速度高8位
									motor.motor_speed, 					//速度低8位
									motor.motor_acc_speed, 				//加速度
									motor.synchronous, 					//多机同步
									0x6b};								//校验

		for(char i = 0; i < 8; i++)
		{
			while((UART4->SR&0X40)==0);
			UART4->DR = ctrl_speed_arr[i];
		}
	}
	vTaskDelay(1);
}

//底盘电机同步函数
void usart_ctrl_chassis_motor_synchronous()
{
	char synchronous_move[4] = {0x00, 0xff, 0x66, 0x6b};
	
	for(char i = 0; i < 4; i++)
	{
		while((UART4->SR&0X40)==0);
		UART4->DR = synchronous_move[i];    
	}

	vTaskDelay(1);
}

//设置回零位置ID1设置回零
void set_gimbal_motor_zero(steeping_motor motor)
{
	char set_zero[5] = {motor.motor_ID, 0x93, 0x88, 0x01, 0x6b};//设置回零指令			

	for(char i = 0; i < 5; i++)
	{
		while((USART3->SR&0X40)==0);
		USART3->DR = set_zero[i];    
	}	
}

//触发回零
void gimbal_motor_return_zero(steeping_motor motor)
{
	char set_zero[5] = {motor.motor_ID, 0x9a, 0x00, 0x00, 0x6b};//触发回零指令	

	for(char i = 0; i < 5; i++)
	{
		while((USART3->SR&0X40)==0);
		USART3->DR = set_zero[i];    
	}
	vTaskDelay(1);
}

//------------不带RTOS的方向控制----------------
static steeping_motor MOTOR[4];

void motor_soft_Init()
{
	for(char i = 0;i < 4; i++) 
	{
		MOTOR[i].motor_ID = i + 1;			//电机ID
		MOTOR[i].motor_acc_speed = 200;		//默认电机加速度
		MOTOR[i].synchronous = 0;
	}

	//电机直行方向
	MOTOR[0].motor_direction = 1;
	MOTOR[1].motor_direction = 0;
	MOTOR[2].motor_direction = 1;
	MOTOR[3].motor_direction = 0;
}

//解算速度
void change_xyw_speed_no_quene(int x, int y, int w)
{
	//速度融合
	int motor_out_speed[4];

	motor_out_speed[0] = x - y - w;
	motor_out_speed[1] = x + y + w;
	motor_out_speed[2] = x + y - w;
	motor_out_speed[3] = x - y + w;

	//方向变量复位
	MOTOR[0].motor_direction = MOTOR[2].motor_direction = 1;
	MOTOR[1].motor_direction = MOTOR[3].motor_direction = 0;

	for(char i = 0; i<4; i++) 
	{
		if(motor_out_speed[i] < 0)//方向未负，改变方向和速度变为正数
		{
			MOTOR[i].motor_direction = !MOTOR[i].motor_direction;	
			motor_out_speed[i] = motor_out_speed[i] * -1;
		}
	}

	//写入
	for(char i = 0; i<4; i++) 
	{
		MOTOR[i].motor_speed = motor_out_speed[i];
		usart_ctrl_chassis_motor(MOTOR[i], 1);
	}

	usart_ctrl_chassis_motor_synchronous();

}

//脉冲控制初始化
void MOTOR_UP_Down_Init(void) 
{
	GPIO_InitTypeDef  GPIO_InitStructure;
	
	RCC_AHB1PeriphClockCmd(RCC_AHB1Periph_GPIOE,ENABLE); 	
	
	GPIO_InitStructure.GPIO_Pin = GPIO_Pin_0 ;   //方向	
	GPIO_InitStructure.GPIO_Mode = GPIO_Mode_OUT;
	GPIO_InitStructure.GPIO_Speed = GPIO_Speed_100MHz;
	GPIO_InitStructure.GPIO_OType = GPIO_OType_PP;
	GPIO_InitStructure.GPIO_PuPd = GPIO_PuPd_DOWN;
	GPIO_Init(GPIOE, &GPIO_InitStructure);

  GPIO_InitStructure.GPIO_Pin = GPIO_Pin_9;	//配置PE9为步进（STP）信号
  GPIO_InitStructure.GPIO_Mode = GPIO_Mode_OUT;
  GPIO_InitStructure.GPIO_Speed = GPIO_Speed_100MHz;
  GPIO_InitStructure.GPIO_OType = GPIO_OType_PP;
  GPIO_InitStructure.GPIO_PuPd = GPIO_PuPd_NOPULL;
  GPIO_Init(GPIOE, &GPIO_InitStructure);
	RCC_AHB1PeriphClockCmd(RCC_AHB1Periph_GPIOE, ENABLE);
	
	GPIO_PinAFConfig(GPIOE, GPIO_PinSource9, GPIO_AF_TIM1);

  TIM_Cmd(TIM1, ENABLE);
}

//方向选择
void Cloud_Turn(uint16_t dir)
{
			if(dir)
      {
				GPIO_ResetBits(GPIOE,GPIO_Pin_0);
			}
			else
			{
				GPIO_SetBits(GPIOE,GPIO_Pin_0);					
			}
}

//脉冲升降控制
void Claw_Up_Down(uint16_t dir,uint16_t dis)//0下降 1上升
{
		Cloud_Turn(dir);
		for(int i = 0; i < dis; i++)
        {
            GPIO_SetBits(GPIOE, GPIO_Pin_9);
            delay_us(50);
            GPIO_ResetBits(GPIOE, GPIO_Pin_9);
            delay_us(50);
        }
    delay_ms(500);
}

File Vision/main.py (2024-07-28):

r"""
*********************************************
                   _ooOoo_
                  o8888888o
                  88" . "88
                  (| -_- |)
                  O\  =  /O
               ____/`---'\____
             .'  \\|     |//  `.
            /  \\|||  :  |||//  \
           /  _||||| -:- |||||-  \
           |   | \\\  -  /// |   |
           | \_|  ''\---/''  |   |
           \  .-\__  `-`  ___/-. /
         ___`. .'  /--.--\  `. . __
      ."" '&lt;  `.___\_&lt;|>_/___.'  >'"".
     | | :  `- \`.;`\ _ /`;.`/ - ` : | |
     \  \ `-.   \_ __\ /__ _/   .-` /  /
======`-.____`-.___\_____/___.-`____.-'======
                   `=---='

			佛祖保佑       工创省一
^^^^^^^^^^^^^^^^^^^^^^^^^^^^^^^^^^^^^^^^^^^^^
"""
import json
import math
import multiprocessing
import time

import numpy as np
from UART import UART
import detector
import cv2

# --------------用于调试的库--------------
from img_trans import VideoStreaming

#region 参数加载
COLOR_dict = {
    0:'R',
    1:'G',
    2:'B'
}
COLOR_dict_reverse = {
    'R':0,
    'G':1,
    'B':2
}

thresholds = [
    #[low_h, low_s, low_v], [high_h, high_s, high_v]
    ([0, 0, 0], [255, 255, 255]),
    ([0, 0, 0], [255, 255, 255]),
    ([0, 0, 0], [255, 255, 255]),
]
# 读取阈值
for i in range(3):
    try:
        with open(f'{COLOR_dict[i]}.json', 'r') as f:
            thresholds[i] = json.load(f)
    except:
        pass
    
CIRCLE_POINT1 = (100, 100)
CIRCLE_R1 = 50
try:        # 读取转盘基准圆心和半径
    with open('circle1.json', 'r') as f:
        data = json.load(f)
        CIRCLE_POINT1 = tuple(data['point'])
        CIRCLE_R1 = data['r']
except FileNotFoundError:
    pass

CIRCLE_POINT2 = (100, 100)
CIRCLE_R2 = 50
try:
    with open('circle2.json', 'r') as f:
        data = json.load(f)
        CIRCLE_POINT2:tuple[int, int] = tuple(data['point'])
        CIRCLE_R2:int = data['r']
except FileNotFoundError:
    pass

MINVAL = 0
MAXVAL = 255
try:        # 直线canny算子的参数
    with open('line.json', 'r') as f:
        data = json.load(f)
        MINVAL = data['minval']
        MAXVAL = data['maxval']
except FileNotFoundError:
    pass


# 物料识别的开闭运算参数
COLOR_COLSE = 0
COLOR_OPEN = 1
try:
    with open('color_oc.json', 'r') as f:
        data = json.load(f)
        COLOR_COLSE = data['close']
        COLOR_OPEN = data['open']
except FileNotFoundError:
    pass

CIRCLE_OPEN = 0 
CIRCLE_CLOSE = 1
try:
    with open('circle_oc.json', 'r') as f:
        data = json.load(f)
        CIRCLE_OPEN = data['open']
        CIRCLE_CLOSE = data['close']
except FileNotFoundError:
    pass

LINE_OPEN = 0
LINE_CLOSE = 1
try:
    with open('line_oc.json', 'r') as f:
        data = json.load(f)
        LINE_OPEN = data['open']
        LINE_CLOSE = data['close']
except FileNotFoundError:
    pass
# endregion


class Solution(detector.ColorDetector, detector.LineDetector, detector.CircleDetector):     # type: ignore
    def __init__(self, ifdebug:bool=False):
        """
        * ifdebug: 是否开启远程调试，此功能可以将识别过程中的重要中间图像通过远程图传传回本地电脑
        """
        self.init_part1()
        self.ser = UART()
        self.cap = cv2.VideoCapture(0)
        if not self.cap.isOpened():
            self.cap = cv2.VideoCapture(1)
            print('摄像头0失效')

        self.debug = ifdebug

        if self.debug:
            self.streaming = VideoStreaming('192.168.137.141', 8000)
            self.streaming.connecting()
            self.streaming.start()

    def init_part1(self):

        # 创建识别器对象
        detector.ColorDetector.__init__(self)
        detector.LineDetector.__init__(self)
        detector.CircleDetector.__init__(self)
        detector.LineDetector.set_threshold(self, (MINVAL, MAXVAL))

        try:
            with open('radius.json', 'r') as f:
                data = json.load(f)
                self.minR = data['minR']
                self.maxR = data['maxR']
        except:
            pass

        self.mask = None
        # 用于测试过程中发送图传的图片
        self.testimg = None

    def read_cap(self) -> cv2.typing.MatLike:
        """
        读取摄像头，并且判断摄像头是否正常，如果不正常则切换摄像头
        * return: 读取到的图像
        """
        while True:
            ret, img = self.cap.read()
            if not ret:
                self.cap = cv2.VideoCapture(1)
                print('摄像头0失效')

                continue
            return img
        
    def send_msg(self, msg:str|int|list[int]|tuple[int, ...], _A:bool=False):
        """从串口发送信号
        ----
        * 发送非迭代数据都会强转成字符串发送
        * 发送两个元素的可迭代数据，会将其补全成三位数，并且包含0 1的前置正负号标志位发送
        * msg: 发送的数据
        * _A: 是否发送角度数据"""
        if isinstance(msg, list) or isinstance(msg, tuple):
            self.ser.send_arr(msg)
        else:
            if not _A:
                self.ser.write(str(msg))
            else:
                # 发送角度数据 
                self.ser.send_angle(msg)       # type: ignore 

        # 清除串口缓存
        while self.ser.in_waiting > 0:
            time.sleep(0.1)
            self.ser.ori_read(self.ser.in_waiting)


    def Detect_color(self, _colorindex:int):
        """颜色识别
        * _colorindex: 颜色索引，0红 1绿 2蓝
        * return: 是否识别到颜色(bool)"""
        self.set_threshold(thresholds[_colorindex])       # 设置阈值
        
        while True:
            self.img = self.read_cap()
            self.img = self.img[130:370, :]
            mask = self.filter(self.img, COLOR_COLSE, COLOR_OPEN)                                 # 过滤
            if mask is None:
                print('read no img')
                continue
            img, p = self.draw_cycle(mask)
            if self.debug:
                self.streaming.send(img)
            if len(p) == 1:
                print(p)
                # 物料圆区域与夹爪圆区域的重叠面积占比
                Present = circle_intersection_area(p[0][0][0], p[0][0][1], p[0][1], CIRCLE_POINT1[0], CIRCLE_POINT1[1], CIRCLE_R1)/(math.pi*CIRCLE_R1**2)
                print(Present)
                # TODO:需要调试此处Present最小值,保证物料夹取的鲁棒性
                if Present > 0.48:      # 判断物料是否在夹爪内
                    return True

            continue
    
    def CORRECTION_angle(self) -> tuple[bool, int]:
        """校准小车与直线的角度
        * return: 识别到的角度,如果没有识别到直线返回None"""
        while True:
            self.img = self.read_cap()
            self.img = self.img[130:360, :]
            if self.img is None:
                continue
            img, angle = self.get_angle(self.img, close=LINE_CLOSE, _open=LINE_OPEN)
            if self.debug:
                self.streaming.send(img)        # type: ignore
            if angle is not None:
                print(angle)
                angle = round(angle)
                if abs(angle-90) > 0:
                    return False, angle
                else:
                    return True, 0
            continue
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

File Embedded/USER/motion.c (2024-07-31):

#include "motion.h"

static char now_location = 0;


int moving(char location)
{
	static int count_value = 0;
	int difference_value = 0;
	
	if (now_location == 0)
	{
		now_location = location;
		return 0;
	}
	else if (location != now_location)
	{
		difference_value = location - now_location;
		now_location = location;
	}
	count_value++;
	if(count_value == 6) now_location = count_value = 0;
	return 50 * difference_value;
}

//获取放置物品的方向距离函数
int* get_way(char location)
{
	static int out_location[2], count = 0;

	if (now_location == 0)
	{
		out_location[0] = out_location[1] = 0;
		now_location = location;
	}
	else if (location > now_location)
	{
		out_location[0] = (location - now_location) * 700;	//time
		out_location[1] = 50;								//speed
	}
	else if (location < now_location)
	{
		out_location[0] = (now_location -location) * 700;	//time
		out_location[1] = -50;								//speed
	}
	now_location = location;

	count++;
	if (count == 6) now_location = count = 0;	//每三次复位
	return out_location;
}

void location_task(char RGB)
{
    int* location_x_y_data = NULL;
		static int flag_value = 0;
    reset_circle_location_packge();

	while(1)
	{
		SendByte('C',RGB);
		vTaskDelay(100);

		location_x_y_data = NULL;
		location_x_y_data = circle_location_decoding();	// 解算定位x和y

		if(	location_x_y_data != NULL)//接收到数据
		{
			//死区判断
			if(	((location_x_y_data[0] > -circle_dead_area) && (location_x_y_data[0] < circle_dead_area)) &&
				((location_x_y_data[1] > -circle_dead_area) && (location_x_y_data[1] < circle_dead_area)))
			{
				if(flag_value == 1)
					{
							change_xyw_speed_no_quene(0, 0, 0);
							flag_value = 0;
							return;
					}
				flag_value++;
			}

			//分段限幅
			for(char i = 0; i < 2; i++)
			{
				if(location_x_y_data[i] < -circle_second_area) location_x_y_data[i] = -2;
				else if(location_x_y_data[i] > circle_second_area) location_x_y_data[i] = 2;
				else if((location_x_y_data[i] > -circle_second_area) && (location_x_y_data[i] < -1)) location_x_y_data[i] = -1;
				else if((location_x_y_data[i] < circle_second_area) && (location_x_y_data[i]) > 1) location_x_y_data[i] = 1;
			}

			change_xyw_speed_no_quene(location_x_y_data[0], location_x_y_data[1], 0);
		}
	}
	
}

void Line_task()
{
	int* Line_Angle_Data = NULL;
	static int count = 0;
	
	while(1)
    {
				
			SendByte('n','A');
        delay_ms(200);
				
				Line_Angle_Data = Line_Angle_decoding();
			
				if(Line_Angle_Data != NULL)//收到数据
				{
					if(Line_Angle_Data[0] > -Line_dead_area && Line_Angle_Data[0] < Line_dead_area)
						{	
							if(count == 3)
							{
								change_xyw_speed_no_quene(0, 0, 0);
								count = 0;
								return;
							}
							change_xyw_speed_no_quene(0, 0, 0);
							count++;
						}
					
					if(Line_Angle_Data[0] < -Line_second_area) 
						Line_Angle_Data[0] = -2;
					else if(Line_Angle_Data[0] > Line_second_area) 
						Line_Angle_Data[0] = 2;
					else if((Line_Angle_Data[0] > -Line_second_area) && (Line_Angle_Data[0] < -Line_dead_area))
						Line_Angle_Data[0] = -1;
					else if((Line_Angle_Data[0] < Line_second_area) && (Line_Angle_Data[0] > Line_dead_area))
						Line_Angle_Data[0] = 1;
					
					change_xyw_speed_no_quene(0, 0, Line_Angle_Data[0]);
					
				}
				   
    }
}

//获取原料
void Claw_Catch_material(void)
{	
	Claw_Up_Down(0,Material_Height);//下降
	
	ServoAngle(0,Claw_Catch);//抓取角度：225
	delay_ms(300);
	
	ServoAngle(2,Clound_Reset);//云台旋转放置：270
	Claw_Up_Down(1,Material_Height);//升高
	
	Claw_Up_Down(0,Put_Height);//下降
	
	ServoAngle(0,Claw_Open_Small);//松开小角度：200
	delay_ms(100);
	
	Claw_Up_Down(1,Put_Height);//升高
	
	ServoAngle(0,Claw_Open);
	ServoAngle(2,Cloude_Work);//云台旋转归位：90
	delay_ms(100);
}

//将物料放置到地上
void PutOn_Ground(void)
{
	ServoAngle(0,Claw_Open_Big);//松开大角度
	ServoAngle(2,Clound_Reset);//云台旋转从货仓拿取：270
	delay_ms(500);
	
	ServoAngle(0,Claw_Catch);//抓取角度：225
	
	Claw_Up_Down(0,Put_Height);//下降

	Claw_Up_Down(1,Put_Height);//升高

	ServoAngle(2,Cloude_Work);//云台旋转归位：90
	delay_ms(500);
	
	Claw_Up_Down(0,Placement_Height);//下降

	ServoAngle(0,Claw_Open_Big);//松开大角度：150
	delay_ms(100);
	
	Claw_Up_Down(1,Placement_Height);//升高
}
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

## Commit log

2024-05-19 更新ignore
2024-05-19 搭建了初步的cnn神经网络来识别颜色
2024-05-19 添加依赖
2024-05-22 将深度学习方案添加到新的文件夹
2024-05-22 将识别器封装在文件中
2024-05-22 添加直线识别的功能
2024-05-22 添加串口封装
2024-05-22 初步完成了主函数的代码
2024-05-22 更改注释，添加TODO
2024-05-22 将ignore移至根目录
2024-05-22 更新文件夹结构
2024-05-22 重构代码，添加了图传线程
2024-05-22 更改while
2024-05-22 添加依赖，更新ignore
2024-05-26 更改二维码识别，修改了直线识别的形态学操作，删除了无用的方法
2024-05-26 封装远程图传作为单独文件
2024-05-26 重构代码
2024-05-28 添加远程图传客户端代码
2024-05-28 进行膨胀和腐蚀
2024-05-28 调整阈值索引
2024-05-28 使用二维码识别区识别二维码
2024-05-28 更新继承关系
2024-05-28 添加一些todo
2024-05-28 解决已知问题
2024-05-28 重构代码，解决已知问题
2024-05-29 重构代码以处理qr_lst中的多条消息
2024-06-02 添加set threshold方法
2024-06-02 重写父类write函数，添加字符发送的包头包尾修饰器
2024-06-02 重构代码，添加新功能和todo
2024-06-03 在UART类中增加send_pack_int和send_pack_str方法
2024-06-03 添加标注
2024-06-04 修复已知问题
2024-06-05 添加直线识别的MNS变量
2024-06-09 重构代码，使得主从机任务分明
2024-06-09 添加注释，提取变量，添加y0基准点参数
2024-06-09 改为大端字节序
2024-06-10 重构个别方法以适应主文件和测试文件的调用环境
2024-06-10 调整init结构以适应测试文件的继承
2024-06-10 将receive重命名为DEBUG，作为测试文件，初步完成测试功能
2024-06-10 删除冗余代码
2024-06-11 修正了无法对未知长度的串口数据读取的问题
2024-06-11 删除了树莓派上识别二维码的功能
2024-06-23 添加接受图传信息的类
2024-06-24 重构代码：添加继承关系
2024-06-24 修复了创建trackbar传参问题，改变函数名以在字类中可以调用；改变了trackbar的窗口名使其更加明了；解决了直线识别过程too many value to unpack 的问题
    [detector.py]
2024-06-24 重构代码： 添加了调试过程用鼠标来确定色环圆圈的位置功能 添加了调试过程用鼠标来确定直线位置的功能 针对父类的继承作出代码重构整理 针对调试过程添加相关类成员和属性
2024-06-24 添加了保存y基准点坐标的方法
2024-06-25 重构代码，使只显示别的y基准点保存和读取
2024-07-12 添加注释
2024-07-12 减去多余行
2024-07-12 添加readme
2024-07-13 添加新的形参
2024-07-13 更新readme
2024-07-13 更改get_edge为私有方法
2024-07-15 添加了霍夫圆环检测器，并且修改了错误的单词
2024-07-15 添加TODO
2024-07-15 调整数组发送逻辑
2024-07-16 添加阈值保存机制
2024-07-16 添加了基准y0和圆信息的保存机制
2024-07-16 图形处理，排除车辆的部分
2024-07-16 将面积的判断改为半径的判断
2024-07-17 添加注释和TODO，并且解决循环问题
2024-07-17 添加功能测试代码，并且解决已知问题
2024-07-17 解决超出边界的问题
2024-07-17 更改包头包尾
2024-07-17 添加功能测试
2024-07-17 强转返回类型为int
2024-07-18 更改初始阈值表
2024-07-18 添加开闭运算的参数保存机制，并且迁移了一些TODO
2024-07-18 删除了一些注释和TODO
2024-07-18 初步解决变量反复导入的问题
2024-07-18 更新READMA
2024-07-18 更新IP并且添加了图传测试
2024-07-18 添加了图传接收的逻辑
2024-07-18 解决了物料台和地面高度不同导致半径大小不同的问题
2024-07-20 添加了直线canny算子之后的开闭运算的可变参数和保存机制
2024-07-20 添加了错误码发送
2024-07-20 简化代码
2024-07-20 添加了图传的IO输出
2024-07-20 解决了一些问题，更改了与电控的串口信号
2024-07-20 解决if问题
2024-07-20 解决一些实际问题，增加了pylance报错
2024-07-20 不再发送整型而是字符数据
2024-07-20 解决一些pylance的报错问题
2024-07-21 与电控更新了沟通协议
2024-07-21 解决了circle1和2点击的时候不能绘制的问题
2024-07-21 加大了最大识别半径
2024-07-21 如果debug功能开启才启动图传连接
2024-07-21 解决一些问题
2024-07-21 跟电控沟通新的沟通方案
2024-07-21 解决pylance报错，并且更改一些注释
2024-07-21 通过大量的IO操作来进行进程间通信，从而在新的进程中能够发送测试图像
2024-07-21 数组的发送不再发送逗号分隔
2024-07-22 改变send返回值
2024-07-22 解决图传问题和色环点两位数的问题
2024-07-22 尝试解决摄像头失效的问题
2024-07-22 数组发送改为3个长度
2024-07-22 更改发送数组的包头包尾
2024-07-22 解决摄像头失效的问题
2024-07-23 解决pylance报错
2024-07-23 使用新的摄像头失效判别方式
2024-07-23 添加新的函数来读取摄像头同时切换摄像头，添加新的注释
2024-07-23 提取变量
2024-07-23 解决了平均点计算列表反复复位的问题
2024-07-23 更正错误的缩进
2024-07-23 解决平均点计算出错不复位的问题
2024-07-23 对非法信号做相应
2024-07-24 最终版V1
2024-07-24 将直线角度检测参数化，并且让识别更加轻松
2024-07-24 完善角度识别的函数
2024-07-24 添加了发送角度的包头包尾和发送函数
2024-07-24 添加一些参数，并且解决发送角度数据多样包头包尾的冲突
2024-07-24 对angle四舍五入
2024-07-24 修正未加入直线开闭运算导致无法识别的问题
2024-07-24 解决返回不精确的问题
2024-07-24 使用原霍夫直线算法
2024-07-25 将色环死区调整至2
2024-07-25 更新present
2024-07-25 更改返回值并且添加IO输出
2024-07-25 添加LED状态指示灯
2024-07-28 删除多余文件
2024-07-28 解决树莓派引脚文件导入出错的问题
2024-07-28 更新依赖
2024-07-28 更改文件结构
2024-07-28 添加根目录说明文档
2024-07-28 更改错别字
2024-07-28 添加说明文档
2024-07-28 添加模型图片
2024-07-28 添加机器模型
    [42步进电机.SLDASM, 42步进电机支架.SLDPRT, AF同步轮.SLDPRT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]
2024-07-31 添加电控代码
2024-07-31 添加ignore
